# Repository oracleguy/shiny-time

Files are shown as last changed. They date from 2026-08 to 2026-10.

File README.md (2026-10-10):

# Shiny Time
Digital clock and multi-mode countdown timer. Displays the current time or different countdown timers with web configuration.

# Buttons

There are two configurable buttons that when pressed will show the countdown in days to a specific date. There are two day countdown modes:
- Specific Day: A day that repeats once per year. ex. Birthday
- Specific Date: A specific day and year. ex: some special event

The modes and the dates are configurable in the web interface.

The day countdown timer should always show the whole day remaining. For example if the countdown was to December 25th, any time on December 24th, it would read "1".

# Time Countdown Timers

The time countdown timers are used to run shorter countdown timers. When a countdown timer is running, the device displays the time remaining instead of the current time. The countdown timers can be started via the web interface.

# Web Interface

The web interface displays what the device is currently displaying. This interface lets set certain options and start and stop timers.

# Hardware

The device is based on a Raspberry Pi Zero 2W.

## GPIO Expander

The buttons and their integrated lights will be connected to a GPIO epander. This expander is connected via the I2C bus and wires two interrupt pins to the Pi.

## Seven Segment Display

The seven segment display will be used to display the current time or the countdown timers. This display will be connected via the I2C bus.

## Web application architecture

The web interface will be generated as a mostly static site with Zola. It will
not initially use a full single-page application framework such as React or
Angular. A small amount of JavaScript can call the Python API and update the
dashboard, while keeping the interface lightweight for the Raspberry Pi Zero
2W.

The Python application uses Flask 3.1.3 and exposes the WSGI application
through the application factory `create_app`. The production server is
Waitress 3.0.2. The development server can be started with `make server`; the
production WSGI server can be started with `make production-server`.

The application factory accepts an optional device implementation:

```python
app = create_app(device_instance=fake_device)
```

This keeps hardware construction out of module import time and allows the web
application to be tested without Raspberry Pi hardware. In production,
`create_app()` constructs the real device when the application starts.

The API is organized around device state and user actions rather than direct
GPIO operations. Physical buttons and web requests should eventually use the
same application services and timer state machine. The initial endpoints are:

```text
GET /api/health   Basic service health check
GET /api/status   Current device status
```

Timer, configuration, and Wi-Fi setup endpoints will be added behind this
boundary. The frontend and API are intended to be served from the same origin,
so cross-origin configuration should not be necessary.

## HTTP and network security

The device will serve HTTP locally rather than requiring HTTPS certificates on
the Raspberry Pi. This applies to both the normal home-LAN interface and the
setup portal at `http://192.168.4.1`. The setup hotspot is isolated and the
setup authorization code is a physical-presence check, not high-security
authentication.

The device must not be exposed directly to the public Internet or through
router port forwarding. Users who need remote access or who are on an
untrusted network should provide the security boundary outside the device,
using a VPN or a reverse proxy that terminates HTTPS. The application should
never log Wi-Fi passwords.

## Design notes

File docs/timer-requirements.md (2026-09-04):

# Timer Requirements

The physical timer should make common countdowns quick to create without turning the clock into a menu-driven controller. Detailed or unusual timer configuration belongs in the web UI.

## Timer states

- **Idle:** The normal clock is displayed.
- **Setting:** The user is choosing a duration.
- **Running:** The countdown is active.
- **Paused:** The countdown is stopped but can resume.
- **Finished:** The timer has reached zero and requires acknowledgement.

## Physical controls

### +1 minute

- Short press from Idle: enter timer-setting mode and add one minute.
- Short press while Setting or Paused: add one minute.
- Hold: repeat additions automatically.
- Repetition begins with one-minute increments, accelerates over time, and may switch to five-minute increments for rapidly entering longer durations.

### Start/Stop

- Short press while Setting: start the countdown.
- Short press while Running: pause the countdown.
- Short press while Paused: resume the countdown.
- Hold for approximately two seconds: cancel the timer and return to the clock.

## Timer limits and display format

- The maximum physical timer duration is 99 hours and 59 minutes.
- Below 100 minutes remaining, display minutes and seconds as `MM:SS`.
- At 100 minutes or more remaining, display hours and minutes as `HH:MM`.
- A long timer switches to `MM:SS` when it drops below 100 minutes.

Example:

```text
02:00  hours:minutes
01:40  hours:minutes
99:59  minutes:seconds
00:12  minutes:seconds
```

## Completion

- At zero, enter the Finished state and display `DONE`.
- The timer-finished alert should be visible briefly and use a distinct LED pattern.
- Any front-button press acknowledges the alert and returns to the clock.

## Interaction boundaries

- Favorite date overlays must not hide a Running or Paused timer.
- Setup mode takes precedence over the timer display.
- The timer continues running only when its state is Running; entering Setup should not silently change the timer state unless explicitly specified by the implementation.
- The web UI may support more advanced timer configuration, but the physical controls should remain limited to the simple flow above.

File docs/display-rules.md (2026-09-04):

# Display Rules

The device uses a four-digit seven-segment display. The display should show one clear state at a time and avoid trying to present complex configuration.

## Display precedence

The highest applicable priority wins:

1. Factory-reset confirmation
2. Wi-Fi Setup mode
3. Timer-finished alert
4. Active timer
5. Favorite date overlay
6. Normal clock

A higher-priority state blocks lower-priority overlays. Only one temporary message may be active at a time.

## Default clock

When no higher-priority state is active, display local time as `HH:MM`.

## Timer display

- Timers with less than 100 minutes remaining display `MM:SS`.
- Timers with 100 minutes or more remaining display `HH:MM`.
- A long timer switches to `MM:SS` once it drops below 100 minutes, so the display becomes more precise near completion.
- The maximum timer value is 99 hours and 59 minutes.

Example:

```text
01:40  hours:minutes
99:59  minutes:seconds
```

## Favorite date overlays

- Favorite 1 and Favorite 2 show their configured date countdown as a temporary overlay.
- Date countdowns display whole calendar days only, without hours or minutes.
- On December 24, a Christmas countdown displays `1` at any time of day.
- At any time on December 25, it displays `0`.
- Recurring dates roll forward to their next occurrence.
- The overlay automatically returns to the clock after a few seconds.
- Favorite overlays do not hide an active or paused timer.

## Status messages

Use short seven-segment-friendly codes where the display can render them clearly:

| Display | Meaning |
|---|---|
| `SETU` | Setup mode active |
| Four digits | Setup authorization code |
| `SCAN` | Scanning for Wi-Fi networks |
| `JOIN` | Testing the selected Wi-Fi connection |
| `GOOD` | Wi-Fi connection succeeded |
| `FAIL` | Wi-Fi connection failed |
| `DONE` | Timer finished |
| `rSEt` | Factory-reset warning or progress |

If a word is not legible on the specific display, use a numeric status code instead.

## Timer-finished alert

When a timer reaches zero:

- Display `DONE`.
- Use the timer-alert LED pattern.
- Keep the alert visible briefly, then return to the clock.
- Continue a less intrusive LED reminder until any front-button press acknowledges it.

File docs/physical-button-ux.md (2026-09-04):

# Physical Button UX

The physical interface should stay simple: it supports the common timer actions without becoming a menu system. Complex configuration belongs in the web UI.

## Front buttons

The device has four illuminated front buttons:

| Button | Short press | Hold |
|---|---|---|
| **Favorite 1** | Show its configured date countdown as a temporary overlay | Same action; hold behavior may be extended later |
| **Favorite 2** | Show its configured date countdown as a temporary overlay | Same action; hold behavior may be extended later |
| **+1 minute** | Add 1 minute to the timer | Repeat additions; accelerate over time |
| **Start/Stop** | Contextual start, pause, or resume | Cancel the timer and return to the clock |

### Timer behavior

- From the clock, pressing **+1 minute** enters timer-setting mode and adds one minute.
- While setting a timer, pressing **Start/Stop** begins the countdown.
- Holding **+1 minute** repeats additions quickly. It starts with 1-minute increments, then accelerates to rapid repeats and eventually 5-minute increments, making durations such as 20 or 30 minutes quick to enter.
- While running, **Start/Stop** pauses the timer; pressing it again resumes the countdown.
- While paused, **+1 minute** can add more time.
- Holding **Start/Stop** for about two seconds cancels the timer and returns to the normal clock display. This prevents an accidental short press from destroying a running timer.

## LEDs

Each button has an independently controlled LED. LEDs should communicate the current state at a glance—for example, indicating the active timer state, paused state, or available shortcut—without requiring a menu or text label.

## Favorite buttons and date overlays

Favorite 1 and Favorite 2 initially provide quick access to two configured date countdowns. A date countdown is shown as a temporary overlay, then the display returns to the clock. The Favorite buttons should remain extensible so they can later trigger other configured functions through the web UI.

## Separate Setup button

Use a separate recessed **Setup** button rather than placing setup controls in the everyday front interface. It is reserved for:

- Wi-Fi onboarding and setup mode
- Re-entering or changing device configuration
- Factory reset, using a deliberate long-press sequence

The web UI handles detailed timer, date, favorite, display, and device configuration.

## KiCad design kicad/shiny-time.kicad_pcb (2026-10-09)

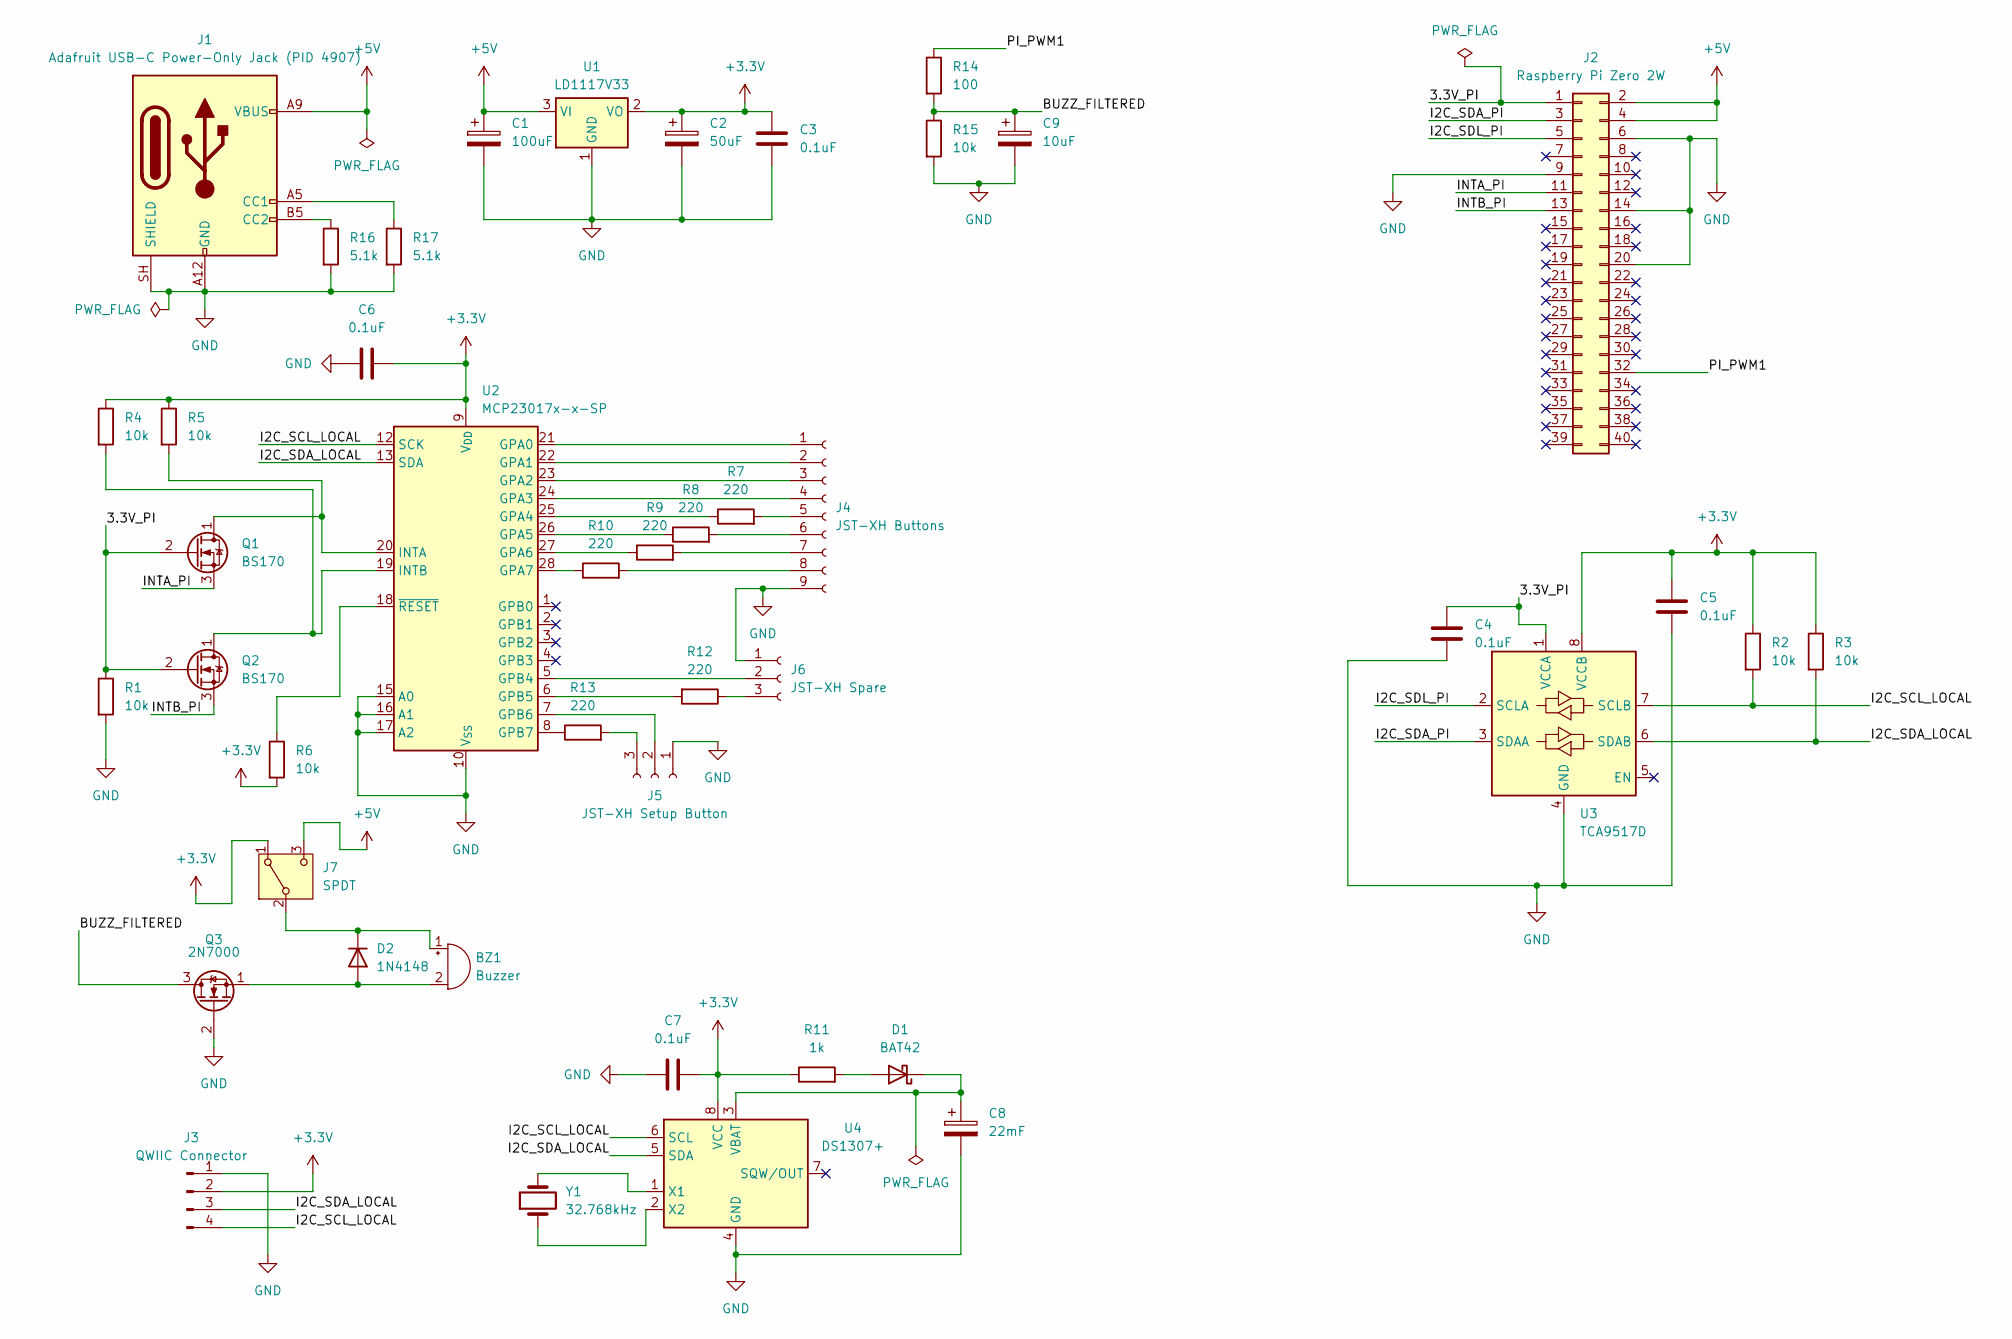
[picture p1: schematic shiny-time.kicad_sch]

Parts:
BZ1: Buzzer; Buzzer_12x9.5RM7.6
C1: 100uF; CP_Radial_D5.0mm_P2.00mm; Digikey_PN 1189-1224-ND
C2: 50uF; CP_Radial_D5.0mm_P2.00mm; Digikey_PN 1189-1148-ND
C3, C4, C5, C6, C7: 0.1uF; C_Disc_D5.0mm_W2.5mm_P2.50mm; Digikey_PN 399-4264-ND
C8: 22mF; CP_Radial_D12.5mm_P5.00mm; Digikey_PN 399-18542-ND
C9: 10uF; C_Disc_D5.0mm_W2.5mm_P5.00mm; Digikey_PN 399-13968-ND
D1: BAT42; D_DO-35_SOD27_P10.16mm_Horizontal; Digikey_PN 497-2495-1-ND
D2: 1N4148; D_DO-35_SOD27_P7.62mm_Horizontal; Digikey_PN 1N4148FS-ND
J1: Adafruit USB-C Power-Only Jack (PID 4907); USB_C_Receptacle_GCT_USB4125-xx-x_6P_TopMnt_Horizontal
J2: Raspberry Pi Zero 2W; Raspberry_Pi_Zero_Socketed_THT_FaceDown_MountingHoles; Digikey_PN 2223-SSK04-FPH-254-B20-ND
J3: QWIIC Connector; JST_SH_BM04B-SRSS-TB_1x04-1MP_P1.00mm_Vertical
J4: JST-XH Buttons; JST_XH_B9B-XH-A_1x09_P2.50mm_Vertical
J5: JST-XH Setup Button; JST_XH_B3B-XH-A_1x03_P2.50mm_Vertical
J6: JST-XH Spare; JST_XH_B3B-XH-A_1x03_P2.50mm_Vertical
J7: SPDT; SW_E-Switch_EG1271_SPDT; Digikey_PN EG1918-ND
Q1, Q2: BS170; TO-92_Inline; Digikey_PN BS170-ND
Q3: 2N7000; TO-92_Inline; Digikey_PN 2N7000FS-ND
R1, R2, R3, R4, R5, R6, R15: 10k; R_Axial_DIN0204_L3.6mm_D1.6mm_P5.08mm_Horizontal; Digikey_PN CF18JT10K0CT-ND
R7, R8, R9, R10, R12, R13: 220; R_Axial_DIN0204_L3.6mm_D1.6mm_P5.08mm_Horizontal; Digikey_PN CF18JT220RCT-ND
R11: 1k; R_Axial_DIN0204_L3.6mm_D1.6mm_P5.08mm_Horizontal; Digikey_PN CF18JT1K00CT-ND
R14: 100; R_Axial_DIN0204_L3.6mm_D1.6mm_P5.08mm_Horizontal; Digikey_PN CF18JT100RCT-ND
R16, R17: 5.1k; R_Axial_DIN0204_L3.6mm_D1.6mm_P5.08mm_Horizontal; Digikey_PN S5.1KCACT-ND
U1: LD1117V33; TO-220-3_Vertical; Digikey_PN 497-1491-5-ND
U2: MCP23017x-x-SP; DIP-28_W7.62mm; Digikey_PN MCP23017-E/SP-ND
U3: TCA9517D; SOIC-8_3.9x4.9mm_P1.27mm; Digikey_PN 296-39221-1-ND
U4: DS1307+; DIP-8_W7.62mm; Digikey_PN DS1307+-ND
Y1: 32.768kHz; Crystal_Round_D2.0mm_Vertical; Digikey_PN 535-9032-ND

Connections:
+3.3V: C2.1, C3.1, C5.1, C6.2, C7.2, J3.2, J7.1 (A), R2.1, R3.1, R4.1, R5.1, R6.2, R11.1, U1.2 (VO), U2.9 (V_{DD}), U3.8 (VCCB), U4.8 (VCC)
+5V: C1.1, J1.A9 (VBUS), J1.B9 (VBUS), J2.2, J2.4, J7.3 (C), U1.3 (VI)
/3.3V_PI: C4.1, J2.1, Q1.2 (G), Q2.2 (G), R1.1, U3.1 (VCCA)
/BUZZ_FILTERED: C9.1, Q3.3 (D), R14.2, R15.1
/I2C_SCL_LOCAL: J3.4, R2.2, U2.12 (SCK), U3.7 (SCLB), U4.6 (SCL)
/I2C_SDA_LOCAL: J3.3, R3.2, U2.13 (SDA), U3.6 (SDAB), U4.5 (SDA)
/I2C_SDA_PI: J2.3, U3.3 (SDAA)
/I2C_SDL_PI: J2.5, U3.2 (SCLA)
/INTA_PI: J2.11, Q1.3 (S)
/INTB_PI: J2.13, Q2.3 (S)
/PI_PWM1: J2.32, R14.1
GND: C1.2, C2.2, C3.2, C4.2, C5.2, C6.1, C7.1, C8.2, C9.2, J1.A12 (GND), J1.B12 (GND), J1.SH (SHIELD), J2.6, J2.9, J2.14, J2.20, J3.1, J4.9, J5.1, J6.1, Q3.2 (G), R1.2, R15.2, R16.2, R17.2, U1.1 (GND), U2.10 (V_{SS}), U2.15 (A0), U2.16 (A1), U2.17 (A2), U3.4 (GND), U4.4 (GND)
unnamed: BZ1.1 (+), D2.1 (K), J7.2 (B)
unnamed: BZ1.2 (-), D2.2 (A), Q3.1 (S)
unnamed: D1.2 (A), R11.2
unnamed: C8.1, D1.1 (K), U4.3 (VBAT)
unnamed: J1.A5 (CC1), R17.1
unnamed: J1.B5 (CC2), R16.1
unnamed: J4.1, U2.21 (GPA0)
unnamed: J4.2, U2.22 (GPA1)
unnamed: J4.3, U2.23 (GPA2)
unnamed: J4.4, U2.24 (GPA3)
unnamed: J4.5, R7.2
unnamed: J4.6, R8.2
unnamed: J4.7, R9.2
unnamed: J4.8, R10.2
unnamed: J5.2, U2.7 (GPB6)
unnamed: J5.3, R13.2
unnamed: J6.2, U2.5 (GPB4)
unnamed: J6.3, R12.1
unnamed: Q1.1 (D), R5.2, U2.20 (INTA)
unnamed: Q2.1 (D), R4.2, U2.19 (INTB)
unnamed: R7.1, U2.25 (GPA4)
unnamed: R8.1, U2.26 (GPA5)
unnamed: R9.1, U2.27 (GPA6)
unnamed: R10.1, U2.28 (GPA7)
unnamed: R12.2, U2.6 (GPB5)
unnamed: R13.1, U2.8 (GPB7)
unnamed: R6.1, U2.18 (~RESET)
unnamed: U4.1 (X1), Y1.2
unnamed: U4.2 (X2), Y1.1

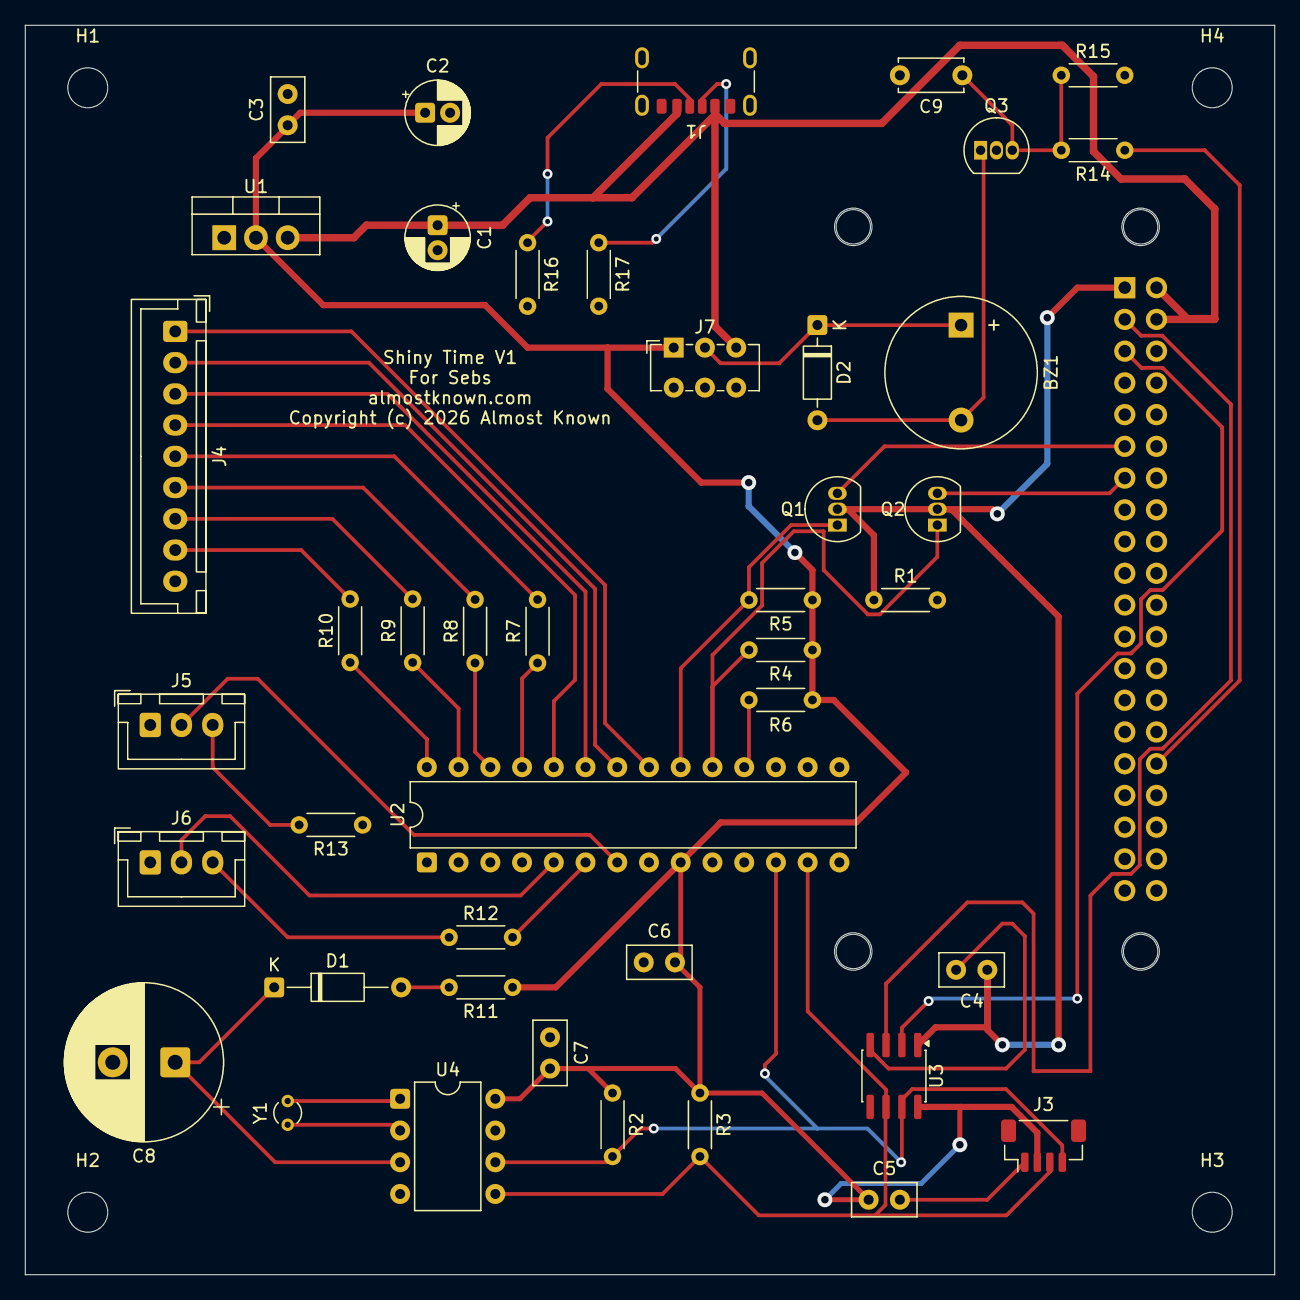
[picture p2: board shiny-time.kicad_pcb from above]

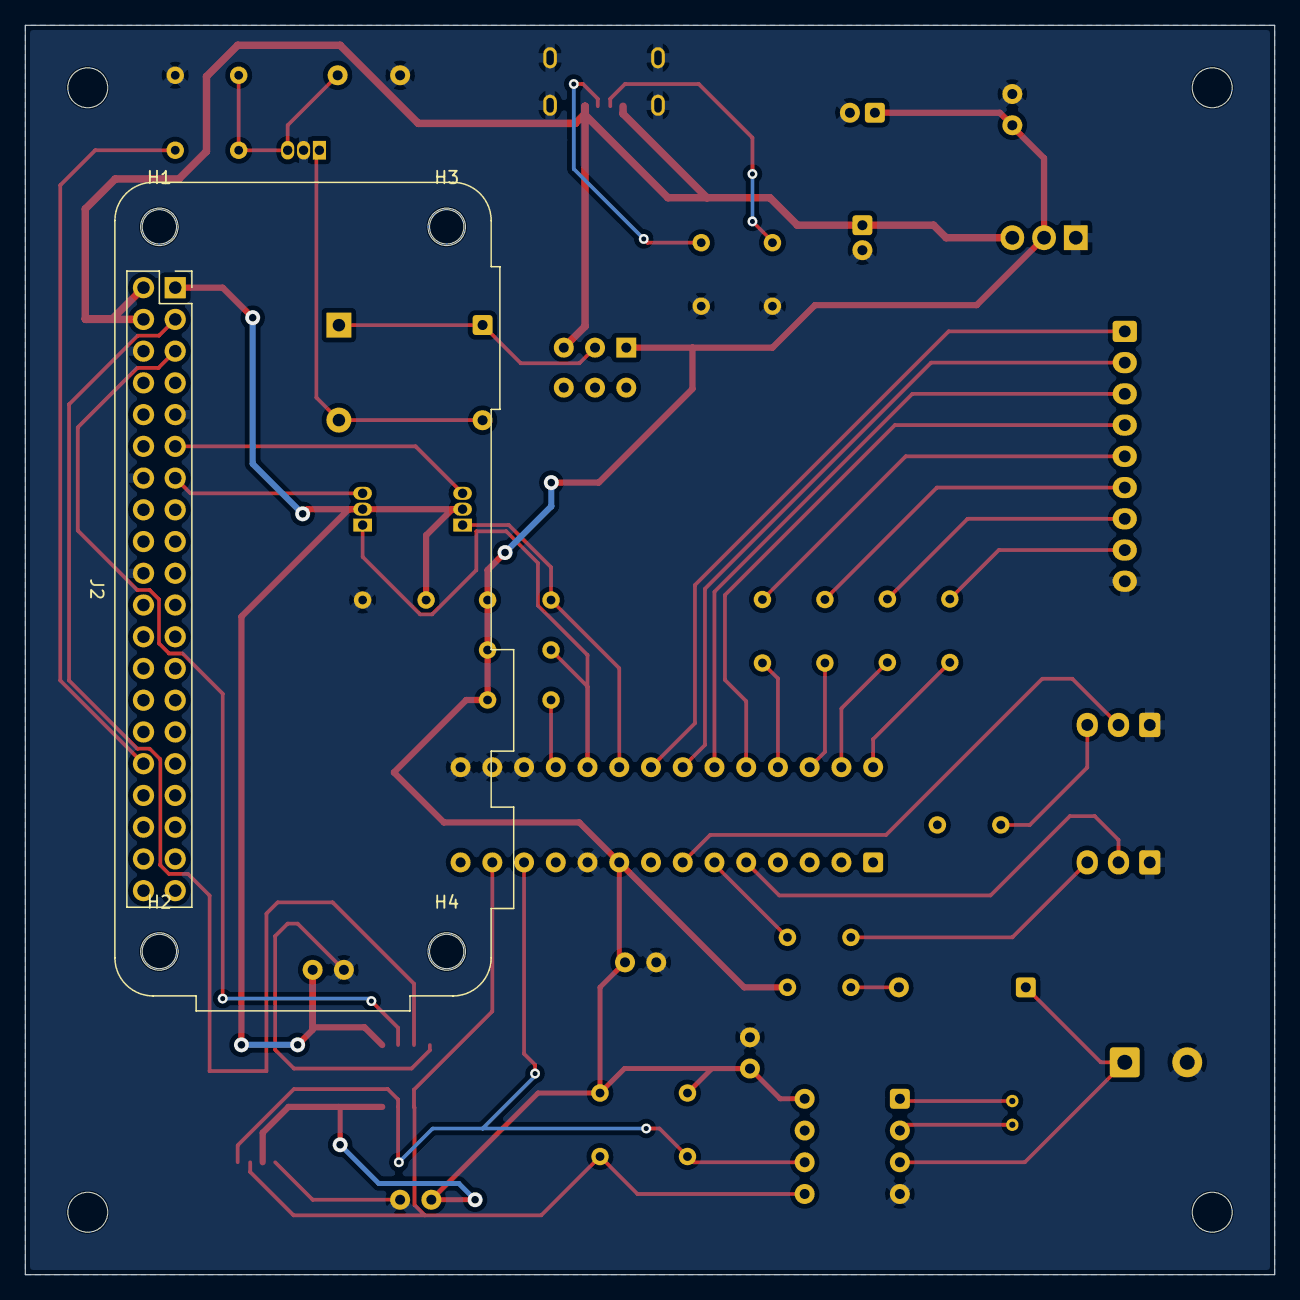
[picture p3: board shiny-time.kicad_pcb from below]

Board: 2 copper layers, 100.0 x 100.0 mm, 52 parts (5 on the bottom side), 41 nets.

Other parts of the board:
H1, H2, H3, H4: MountingHole_3.2mm_M3
H1#2, H2#2, H3#2, H4#2: MountingHole_3mm

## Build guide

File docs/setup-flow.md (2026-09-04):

# Setup Button Requirements

The Setup flow is used rarely and should remain intentionally simple. The four-digit display communicates short status messages and a temporary authorization code; the phone or laptop handles Wi-Fi configuration.

## Entering Setup mode

- Hold the recessed **Setup** button for approximately three seconds.
- Start a temporary, open hotspot with a device-specific SSID such as `Clock-A7F3`.
- Keep the hotspot isolated from the internet and other local devices.
- Generate a new random four-digit authorization code for each Setup session.
- Show the status and code on the four-digit display, alternating when necessary:

```text
SETU → 4827 → SETU → 4827
```

- Use a new code whenever Setup mode begins; do not use a permanent code.
- End Setup mode after successful configuration, cancellation, or approximately ten minutes of inactivity.

The four-digit code confirms that the person configuring the device is physically near it. It is a presence check, not high-security authentication.

## Captive portal flow

1. The user joins the open `Clock-XXXX` hotspot.
2. The setup page opens automatically when captive-portal detection works.
3. If it does not open automatically, the user navigates to `http://192.168.4.1`.
4. The page asks for the four-digit code currently shown on the display.
5. After the code is accepted, the page presents Wi-Fi configuration.
6. The user selects a network, enters its password, and submits the form.
7. The device tests the new connection before leaving Setup mode.

The portal should provide:

- Nearby network list
- SSID, signal strength, and detected security type
- Password field with show/hide control
- Manual entry for hidden networks
- Connection progress and a clear success or failure message

Automatic captive-portal opening is best effort. The direct local address must always be available as a fallback.

## Four-digit display states

Use a small set of short codes that are legible on a seven-segment display:

| Display | Meaning |
|---|---|
| `SETU` | Setup mode is active |
| Four digits | Current authorization code |
| `SCAN` | Scanning for nearby networks |
| `JOIN` | Testing the selected Wi-Fi connection |
| `GOOD` | Wi-Fi connection succeeded |
| `FAIL` | Wi-Fi connection failed |
| `rSEt` | Factory-reset warning or progress |

If a word is not legible on the specific display, use numeric status codes instead.

## Front LED patterns

Assuming single-color LEDs, use simple patterns rather than requiring users to decode colors:

| State | LED pattern |
|---|---|
| Setup ready / waiting for code | All four LEDs gently pulse together |
| Scanning | Slow left-to-right sweep |
| Testing Wi-Fi | Right-to-left sweep |
| Success | All four LEDs flash twice, then turn off |
| Failure | Three short flashes, repeated periodically |
| Factory reset warning | Rapid synchronized flashing |

## Applying Wi-Fi settings

- Do not erase the existing known-good Wi-Fi profile until the replacement connection succeeds.
- Keep the setup hotspot running while the new connection is being tested.
- On success, show `GOOD`, briefly indicate success with the LEDs, then disable the hotspot.
- On failure, show `FAIL`, keep the hotspot running, and return the user to the Wi-Fi form.
- Do not record Wi-Fi passwords in logs or display them after submission.

## Compatibility guidance

The first version should target ordinary home networks:

- WPA2-Personal: supported
- WPA3-Personal: attempt when supported by the Pi’s hardware, firmware, and OS
- WPA2/WPA3 mixed mode: preferred when a router offers it
- Hidden SSIDs: supported through manual entry
- Enterprise / 802.1X networks: out of scope for the initial setup flow
- Networks requiring a browser-based sign-in: out of scope for the initial setup flow

If a WPA3-only connection fails, explain that the user can temporarily enable WPA2/WPA3 mixed mode or WPA2-Personal on the router.

The implementation should use the supported Raspberry Pi OS networking stack and report detected capabilities where practical. The page should not promise WPA3 support universally because behavior can vary by Raspberry Pi model and wireless firmware.

## Factory reset

- Hold the recessed Setup button for approximately ten seconds to begin factory reset.
- Show `rSEt` and use the rapid LED pattern as a warning before completion.
- Factory reset should remove saved Wi-Fi credentials and device configuration only after the hold threshold is reached.

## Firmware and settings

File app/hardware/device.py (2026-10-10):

from hardware.i2c import get_i2c_bus, DISPLAY_ADDRESS
from adafruit_ht16k33.segments import BigSeg7x4
from hardware.gpio import gpio
from hardware.buttons import buttons
import board

class Device:
    """A class representing the hardware device for the clock."""

    def __init__(self):
        self.i2c = get_i2c_bus()
        self.display = BigSeg7x4(self.i2c, address=DISPLAY_ADDRESS)
        self.gpio = gpio(self.i2c)
        self.buttons = buttons(self.gpio)

    def __repr__(self):
        return f"Device(i2c={self.i2c}, display={self.display}, gpio={self.gpio})>"

    def get_board_id(self) -> str | None:
        """Get the board ID from the device."""
        return board.board_id

    def set_display_value(self, value: str):
        """Set the display value on the device."""
        self.display.print(value)
        return

    def set_display_brightness(self, brightness: int):
        """Set the display brightness on the device."""
        self.display.brightness = brightness
        return

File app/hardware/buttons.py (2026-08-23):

from hardware.gpio import gpio
import digitalio
from adafruit_blinka.board.raspberrypi.raspi_40pin import D0
import board

BUTTON_COUNT = 4

class buttons:
    """A class representing the buttons on the hardware device."""

    def __init__(self, gpio: gpio):
        self.gpio = gpio
        self.button_states = [False] * BUTTON_COUNT
        self.lamp_states = [False] * BUTTON_COUNT
        self.setup_buttons()
        self.setup_interrupts()

    def read_buttons(self) -> list[bool]:
        """Read the current state of the buttons."""
        for i in range(BUTTON_COUNT):
            self.button_states[i] = self.gpio.read_pin(i)
        return self.button_states

    def setup_buttons(self):
        """Set up the buttons as input pins."""
        self.gpio.setup_pins(list(range(BUTTON_COUNT)), "input")
        self.gpio.setup_pins(list(range(BUTTON_COUNT - 1, BUTTON_COUNT * 2)), "output")

    def set_lamp_state(self, button_index: int, state: bool):
        """Set the state of the lamp associated with a button."""
        if 0 <= button_index < BUTTON_COUNT:
            self.lamp_states[button_index] = state
            self.gpio.write_pin(button_index + BUTTON_COUNT, state)
        else:
            raise IndexError("Button index out of range.")

    def get_lamp_states(self) -> list[bool]:
        """Get the current state of the lamps."""
        return self.lamp_states

    def setup_interrupts(self):
        """Set up interrupts for the buttons."""
        digitalio.DigitalInOut(getattr(board, "D1")).switch_to_input(pull=digitalio.Pull.UP)

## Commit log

2026-08-23 Work on buttons
2026-09-07 Add schematic
    [shiny-time.kicad_pcb, shiny-time.kicad_sch]
2026-09-07 ERC fixes
    [shiny-time.kicad_sch]
2026-09-12 Assign footprints and start pcb
    [shiny-time.kicad_pcb, shiny-time.kicad_sch]
2026-09-17 Add pi holes
    [shiny-time.kicad_pcb]
2026-09-19 More schematic work
    [shiny-time.kicad_pcb, shiny-time.kicad_sch]

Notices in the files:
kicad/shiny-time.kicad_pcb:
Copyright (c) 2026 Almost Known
